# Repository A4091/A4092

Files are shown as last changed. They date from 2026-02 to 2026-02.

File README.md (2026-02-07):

# A4092 — A Modern Successor to the A4091

The A4092 is a modern re-implementation of Dave Haynie's classic A4091 Zorro
III SCSI controller for the Commodore Amiga. It retains a lot of the proven
architecture and the NCR/LSI 53C710 SCSI controller at its core, while
replacing obsolete and unobtainable components with modern equivalents that are
more readily available today.

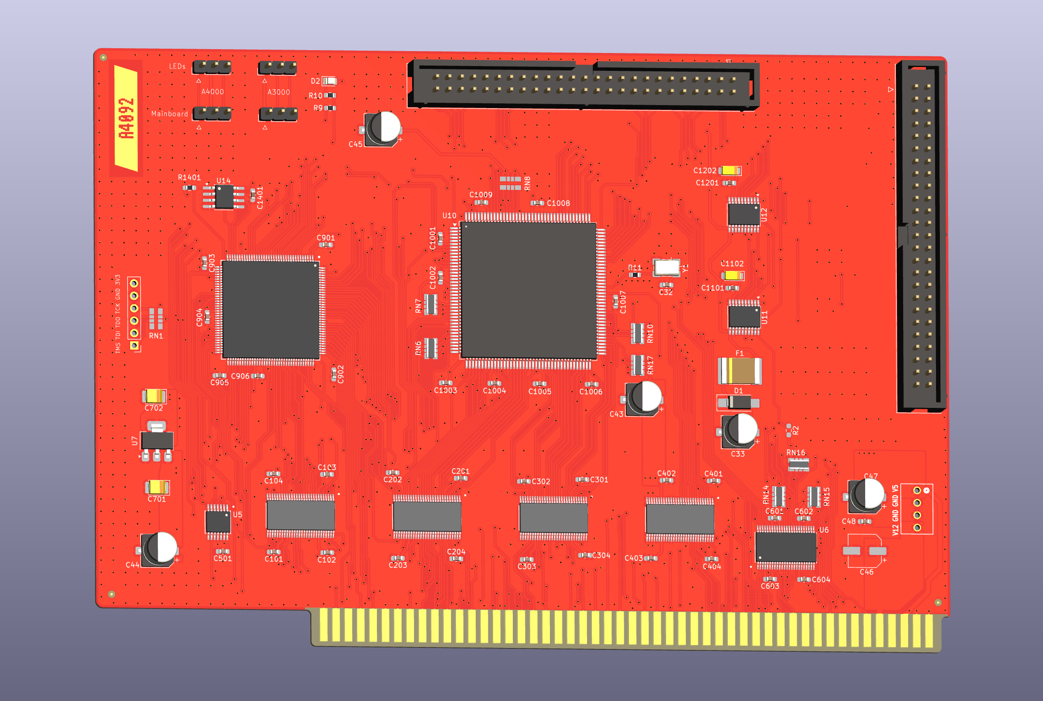
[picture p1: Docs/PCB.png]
PCB


And also as a real PCB (REV A):

Real PCB

## What's New

### CPLD Instead of GALs

The original A4091 used eight discrete GALs (ATF22V10 and similar) programmed
with WinCUPL to implement all bus interface, AutoConfig, address decoding,
arbitration, and SCSI control logic. The A4092 consolidates all of this
into a single Xilinx XC95144XL CPLD. This brings several advantages:

- Field-updatable logic — no need to pull and reprogram individual GAL chips
- No soldering and no sockets required for upgrading the liogic.
- More logic resources and routing flexibility than the original GAL array
- Eliminates dependence on increasingly scarce GAL parts
- The original WinCUPL equations have been rewritten from scratch in Verilog for the CPLD

### SPI Flash Instead of EPROM

The parallel EPROM used for the A4091's boot ROM has been replaced with SPI
Flash memory. Firmware updates no longer require a UV eraser and a dedicated
EPROM programmer — the flash can be reprogrammed in-system.

### Modern SMD Packages

Where the original A4091 used through-hole, PLCC and SOIC packages, the A4092 uses
TSSOP and other modern surface-mount packages (such as 0603 passives). This
reduces the board footprint, improves signal integrity and aligns with current
PCB assembly capabilities.

### Designed for Current Manufacturing

The A4092 is designed to be manufactured with services like JLCPCB or PCBway, using
(mostly) components that are in current production and readily sourced. No hunting for
NOS parts or pulling chips from donor boards.

### AutoConfig in the CPLD

The AutoConfig logic — previously spread across multiple GALs — is now
integrated into the CPLD alongside the rest of the glue logic, resulting in a
cleaner and more maintainable design. 

## What Stays the Same

The A4092 is not a redesign — it is a re-implementation. The core architecture is unchanged:

- NCR/LSI 53C710 SCSI controller
- Zorro III bus interface with the same timing and protocol behavior
- Full compatibility with existing A4091 device drivers and ROM images
- Active SCSI termination
- Internal and external SCSI connectors

## Revisions

- **Revision C** - This is the revision you should build.
- **Revision A** - needs [a number of reworks](https://docs.google.com/document/d/1CN8fwkUjfMrxxf_vMktpmiZ6GXSNA-jGrsVZTGIDl_o/edit?usp=sharing)

## Related Projects

- **A4091** — The original Commodore design by Dave Haynie (1992)

## License



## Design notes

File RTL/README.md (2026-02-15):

# A4092 CPLD RTL

Verilog RTL for the A4092 Zorro III SCSI controller. The design targets a
**Xilinx XC95144XL** CPLD and bridges a **NCR 53C710** (or 53C770) SCSI
controller to the Amiga Zorro III bus. It is a modern re-implementation of the
glue logic found on the Commodore A4091.

## Architecture Overview

```
                        Zorro III Bus
                 ───────────┬───────────
                            │
                     ┌──────┴──────┐
                     │  A4092 CPLD │
                     │  (XC95144XL)│
                     │             │
          ┌──────────┤  Top-level  ├───────────┐
          │          │  A4092.v    │           │
          │          └──┬───┬───┬──┘           │
          │             │   │   │              │
     ┌────┴────┐  ┌─────┴┐  │ ┌-┴─────┐  ┌─────┴────┐
     │Autoconf │  │Buffer│  │ │ DMA   │  │Interrupt │
     │         │  │Ctrl  │  │ │Arbiter│  │Handling  │
     └─────────┘  └──────┘  │ └───┬───┘  └──────────┘
                            │     │
                       ┌────┴-┐ ┌─┴──────┐
                       │SCSI  │ │  DMA   │
                       │Access│ │ Master │
                       └──────┘ └────────┘
                           │
                    ───────┴───────
                     NCR 53C710/770
```

## Module Descriptions

| Module | File | Description |
|---|---|---|
| **A4092** | `A4092.v` | Top-level module. Clock generation, address decoding, data bus muxing, and Zorro III signal assignment. |
| **autoconfig** | `autoconfig.v` | Zorro III Autoconfig (plug-and-play). Presents manufacturer/product ID and accepts base address assignment from the OS. |
| **buffercontrol** | `buffercontrol.v` | Controls external data and address bus buffers -- output enable, direction, and data latching for both slave and DMA master cycles. |
| **dmaarbiter** | `dmaarbiter.v` | Arbitrates between the NCR SCSI chip's DMA requests and the Zorro III bus. Handles bus request/grant handshaking on the 7 MHz arbitration clock. |
| **dmamaster** | `dmamaster.v` | Generates Zorro III bus master cycle timing (FCS, DOE, DS) when the NCR chip performs DMA transfers. |
| **scsiaccess** | `scsiaccess.v` | Manages CPU (slave) access to NCR SCSI registers. Generates AS/DS/SREG strobes to the SCSI chip and converts SLACK to Zorro DTACK. |
| **interrupthandling** | `interrupthandling.v` | Handles SCSI interrupts. Supports both directly-forwarded INT2 and the Zorro III Quick Interrupt protocol with programmable interrupt vectors. |
| **sidregister** | `sidregister.v` | Software-accessible SCSI ID / configuration register. Replaces the hardware DIP switch with a virtual register; also controls external SCSI bus termination. |
| **spirom** | `spirom.v` | SPI flash ROM interface. Bit-bangs SPI read commands to serve firmware to the CPU over Zorro III. |
| **parallelrom** | `parallelrom.v` | Parallel flash ROM interface (active when `USE_SPIROM` is not defined). Directly drives CE/OE/WE lines with configurable wait states. |

## Address Map

Within the card's Autoconfig-assigned 16 MB address space:

| Offset | Range | Peripheral |
|---|---|---|
| `$000000` | `$000000 - $7FFFFF` | Boot ROM (SPI or parallel flash) |
| `$800000` | `$800000 - $87FFFF` | NCR 53C710/770 SCSI registers |
| `$880000` | `$880000 - $8BFFFF` | Interrupt control register |
| `$8C0000` | `$8C0000 - $8FFFFF` | SCSI ID / configuration register |

Address decoding uses `A[23]`, `A[19]`, and `A[18]` in the top-level module.

## Compile-Time Options

Defined at the top of `A4092.v`:

| Define | Default | Description |
|---|---|---|
| `USE_SPIROM` | Defined | Use SPI flash for boot ROM. Undefine for parallel flash. |
| `USE_DIP_SWITCH` | Undefined | Use a physical DIP switch for SCSI ID instead of the virtual `sidregister`. |
| `A22_21_MISSING` | Defined | Address lines A22/A21 are not routed to the CPLD; synthesizes workaround logic. |
| `53C770` | Undefined | When defined, BCLK is an external input from a 53C770. Otherwise the CPLD generates 25 MHz by dividing the 50 MHz oscillator. |

## Autoconfig Identity

| Field | Value |
|---|---|
| Manufacturer ID | 514 (Commodore) |
| Product ID | 84 |
| Serial | 14 |
| ROM vector offset | 512 ($200) |

## Clocks

- **CLK_50M** -- 50 MHz oscillator input, used by SPI ROM and interrupt logic.
- **CLK** (25 MHz) -- Generated internally by dividing CLK_50M by 2 (or external input when `53C770` is defined). Drives the NCR SCSI chip as BCLK and clocks most bus-cycle state machines.
- **C7M** (7.09 MHz) -- Zorro III arbitration clock from the backplane. Used exclusively by the DMA arbiter for bus request timing.

## Building

Requires the Xilinx ISE toolchain (XST, ngdbuild, cpldfit, hprep6).

```
make                 # Synthesize and produce A4092.jed
make timing          # Run timing analysis
make flash           # Program the CPLD via JTAG
make clean           # Remove build artifacts
```

The Makefile supports `USE_DIP_SWITCH=1` to build with hardware DIP switch support.

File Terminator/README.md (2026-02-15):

# A4092 Active SCSI Terminator Case

A 3D-printable snap-fit enclosure for the A4092 (and A4091) Active SCSI Terminator PCB, designed in [OpenSCAD](https://openscad.org/) using the [YAPP Box](https://github.com/mrWheel/YAPP_Box) generator v3.

## Features

- Two-piece snap-fit design (base + lid), no screws required
- Cutout for the IDC50 SCSI connector
- Label embossed/debossed on the lid
- PCB standoffs with alignment pins

## Variants

STL files are provided for several combinations:

| Option | Choices |
|---|---|
| Device | A4091, A4092 |
| Process | FDM (debossed label), Resin/SLA (embossed label) |
| Edge style | Round, Chamfered |

Pre-built STL files follow the naming convention:

```
<device>_terminator_<part>_<process>_<style>.stl
```

For example: `A4092_terminator_lid_fdm_chamfered.stl`

## Building from Source

### Prerequisites

- [OpenSCAD](https://openscad.org/) (the Makefile expects the macOS .app bundle by default)
- [YAPP Box generator v3](https://github.com/mrWheel/YAPP_Box) checked out at `../YAPP_Box/`

### Generating STL Files

```bash
make          # Build all variants
make clean    # Remove generated STL files
```

The Makefile generates all combinations of part, process, and style automatically. To change which devices are built, edit the `DEVICES` variable in the Makefile.

## Printing Tips

- **FDM**: Labels are debossed (engraved into the surface). Use the `fdm` STL variants.
- **Resin/SLA**: Labels are embossed (raised from the surface). Use the `resin` STL variants.
- No supports should be needed for either the base or lid when printed in their default orientation.

## Design Parameters

Key dimensions (defined in `A4092_terminator.scad`):

| Parameter | Value |
|---|---|
| PCB size | 69.6 x 24 mm |
| Wall thickness | 2.0 mm |
| Base/lid plane thickness | 2.0 mm |
| Ridge height | 4.0 mm |

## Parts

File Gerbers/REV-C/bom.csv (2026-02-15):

Designator | Footprint | Quantity | Value | LCSC Part #
C1001, C1003, C1005, C1007, C1009, C101, C102, C103, C104, C1101, C1201, C1401, C201, C202, C203, C204, C301, C302, C303, C304, C401, C402, C403, C404, C48, C501, C601, C602, C603, C604, C901, C902, C903, C904, C905, C906 | 0603 | 36 | 100nF | C14663
C1002, C1004, C1006, C1008, C32 | 0603 | 5 | 10nF | C57112
C1102, C1202 | CP_EIA-3216-10_Kemet-I_HandSolder | 2 | 4.7uF | C7189
C33, C43, C44, C45, C47 | CP_Elec_6.3x7.7 | 5 | 47uF | C369909
C701 | CP_EIA-3528-15_AVX-H_HandSolder | 1 | 10uF | C7194
C702 | CP_EIA-3528-15_AVX-H_HandSolder | 1 | 22uF | C696813
D1 | D_SMA_Handsoldering | 1 | SS24 | C43381
D2 | 0805 | 1 | LED (green) | C965821
F1 | 2920 | 1 | ASMDC185F/33-2 | C3761950
J1, J5 | IDC-Header_2x25_P2.54mm_Vertical | 2 | Conn_02x25_Odd_Even | C221059
J3 | PinHeader_1x03_P2.54mm_Vertical | 1 | TO-LED | C6332196
J4 | PinHeader_1x03_P2.54mm_Vertical | 1 | TO-MB | C6332196
J8 | PinHeader_1x03_P2.54mm_Vertical | 1 | TO-A3000-LED | C6332196
J9 | PinHeader_1x03_P2.54mm_Vertical | 1 | TO-A3000-MB | C6332196
R10 | 0603 | 1 | 2.2k | C4190
R11 | 0603 | 1 | 22 | C23345
R1401 | 0603 | 1 | 10K | C25804
R9 | 0603 | 1 | 120 | C22787
RN10, RN14, RN15, RN16, RN17, RN6, RN7 | BO_CAY16 | 7 | 1K | C784824
U1, U2, U3, U4 | DGG56 | 4 | SN74ABT16543DGGR | C2865087
U10 | PQFP-160_28x28mm_P0.65mm | 1 | NCR53c710 SCSI Host Controller | C9900133089
U11, U12 | TSSOP-20_4.4x6.5mm_P0.65mm | 2 | DS21S07A | C6602097
U14 | SOIC-8_multi | 1 | W25X40CLSN | C19617
U5 | TSSOP14_5P1X4P5_NEX | 1 | 74LVC07APW_118 | C6051
U6 | DGG48 | 1 | SN74ABT16245ADGGR | C130197
U7 | SOT-223-3_TabPin2 | 1 | AMS1117-3.3 | C6186
U9 | 144-TQFP_XIL | 1 | XC95144XL-TQ144 | C1521137
Y1 | Oscillator_SMD_Fox_FT5H_5.0x3.2mm | 1 | Abracon ACO-50MHz | C7431196

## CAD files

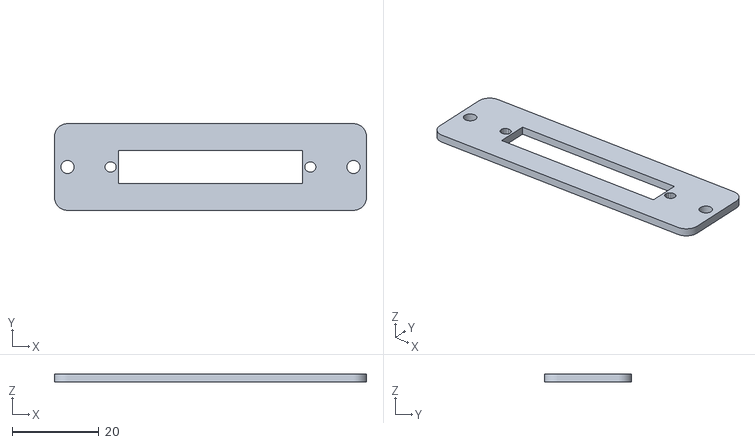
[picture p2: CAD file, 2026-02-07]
Brackets/a4000d_hpdb50.stl
72.0 x 20.0 x 1.80

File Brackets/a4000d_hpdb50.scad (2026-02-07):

$fn = 128;  // smoothness of corners
$thickness = 1.8;
//$holeoffset = -1.3;
$holeoffset = 0;

module rounded_plate(size, radius) {
    hull() {
        for (x = [-1, 1], y = [-1, 1])
            translate([x * (size.x/2 - radius), y * (size.y/2 - radius), 0])
                cylinder(h = size.z, r = radius, center = false);
    }
}

color ("beige") translate ([0,0,0])
    difference () {
        difference() {
            rounded_plate([72, 20, $thickness], radius = 3);
            union() {
                translate ([-33,$holeoffset,-0.1])
                    cylinder(h = $thickness + 0.2, r = 1.5, center = false);
                translate ([33,$holeoffset,-0.1])
                    cylinder(h = $thickness+0.2, r = 1.5, center = false);
            }
        };
 
        translate ([-49.1,-11.1,0]) union()
        {
            translate([27.85,7.35,-0.1])
                cube([42.5,7.5,$thickness + 0.2]);
            translate([26.05,11.1,-0.1])
            {
                scale([2.6/2.4, 1, 1])
                    cylinder(d=2.4, h=$thickness + 0.2, $fn=15);
                translate([46.1,0,0])
                    scale([2.6/2.4, 1, 1])
                        cylinder(d=2.4, h=$thickness + 0.2, $fn=15);
            }
        }
    }

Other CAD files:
Terminator/A4092_terminator.scad

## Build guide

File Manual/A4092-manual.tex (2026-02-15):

%\documentclass[10pt, twoside, openright]{report}
\documentclass[10pt, twoside, openany]{report}
\usepackage[paperwidth=5.5in, paperheight=8.5in,
  left=1.5cm, right=1.5cm, top=6mm, bottom=6mm,
  bindingoffset=0.5cm,
  includehead, includefoot,
  headheight=23pt, headsep=6pt, footskip=24pt]{geometry}
\usepackage[utf8]{inputenc}
\usepackage[T1]{fontenc}
\usepackage{helvet} % Helvetica for a classic technical feel
\renewcommand{\familydefault}{\sfdefault}

% Colors based on your box art
\usepackage{xcolor}
\definecolor{boxblack}{cmyk}{0.6,0.4,0.4,1} % Rich black (C60 M40 Y40 K100)
\definecolor{cranered}{cmyk}{0,1,1,0.28} % Origami Red (converted from #B80000)
\definecolor{lightgrey}{cmyk}{0,0,0,0.12} % Light grey (converted from #E0E0E0)
\definecolor{warninggrey}{cmyk}{0,0,0,0.06} % Warning grey (converted from #F0F0F0)

% Graphics and Formatting
\usepackage{graphicx}
% SVGs are converted to PDFs by Makefile using Inkscape
\usepackage{titlesec}
\usepackage{fancyhdr}
\usepackage{array}    % Column formatting (e.g. >{\centering})
\usepackage{booktabs} % Professional tables
\usepackage{longtable}
\usepackage{pagecolor} % For the black cover
\usepackage{caption}
\usepackage{float}
\usepackage{framed}
\usepackage{enumitem}
\usepackage[colorlinks=false, pdfborder={0 0 0}]{hyperref}
\setlist[itemize]{itemsep=3pt, parsep=0pt, topsep=4pt}
\setlist[enumerate]{itemsep=2pt, parsep=0pt, topsep=4pt}

% No paragraph indentation
\setlength{\parindent}{0pt}
\setlength{\parskip}{0.5em}

% Warning and Caution box styles
\newenvironment{warningbox}{%
  \def\FrameCommand{\fboxsep=3mm \fboxrule=1pt \fcolorbox{black}{warninggrey}}%
  \MakeFramed{\advance\hsize-\width \FrameRestore}}%
{\endMakeFramed}

\newenvironment{cautionbox}{%
  \begin{quote}\itshape\textbf{Caution:} }%
{\end{quote}}

% Header/Footer Configuration
\pagestyle{fancy}
\fancyhf{}
\fancyhead[LE,RO]{\textbf{A4092 User's Guide}}
\fancyhead[RE,LO]{\nouppercase{\leftmark}}
\fancyfoot[C]{\thepage}
\renewcommand{\headrulewidth}{0.4pt}

% Section styling
\titleformat{\chapter}[hang]{\Huge\bfseries\color{cranered}}{}{0pt}{}
\titlespacing*{\chapter}{0pt}{-28pt}{20pt}
\titleformat{\section}{\Large\bfseries}{}{0pt}{}
\titleformat{\subsection}{\large\bfseries}{}{0pt}{}

\begin{document}

% =============================================================================
% COVER PAGE (Black with Red Cranes)
% =============================================================================
\begin{titlepage}
    \newpagecolor{boxblack}
    \color{white}
    \thispagestyle{empty}

    \begin{center}
        \vspace*{1cm}
        

        \vspace{1cm}

        {\fontsize{60}{70}\selectfont \textbf{\textcolor{cranered}{A4092}}} \\
        \vspace{0.5cm}
        {\Huge \textbf{Zorro III SCSI-2}} \\
        \vspace{0.2cm}
        {\LARGE Host Adapter}

        \vfill

        \rule{0.8\textwidth}{0.5pt} \\
        \vspace{0.5cm}
        {\small HIGH PERFORMANCE STORAGE SOLUTION FOR AMIGA COMPUTERS}
        \vspace{1cm}
    \end{center}
\end{titlepage}

% =============================================================================
% FRONT MATTER (White background returns)
% =============================================================================
\nopagecolor
\color{black}

% Blank page
\newpage
\thispagestyle{empty}
\mbox{}

% Reset page counter so cover pages don't count
\setcounter{page}{0}

% Warning page
\newpage
\thispagestyle{empty}
\vspace*{2cm}
\begin{warningbox}
\begin{center}
{\Huge \textbf{WARNING}}
\end{center}

\vspace{0.5cm}

Installation information in this document is for reference only. All installation of internal optional devices or equipment including third-party optional devices or equipment, should be performed by an experienced and knowledgeable technician. All servicing or upgrading of original or optional devices or equipment should also be performed by an experienced and knowledgeable technician.

\vspace{0.5cm}

\textbf{UNAUTHORIZED INSTALLATION, SERVICING OR UPGRADING MAY VOID YOUR WARRANTIES.}
\end{warningbox}

\vspace{2cm}

\noindent This manual provides a general description of various product configurations and features currently planned for inclusion in the product line. The configurations and features described may not be available or otherwise apply to your particular system.

% Copyright page
\newpage
\thispagestyle{empty}

\small
\noindent Copyright \copyright\ 2026 by Stefan Reinauer. This document is licensed under the Creative Commons Attribution-ShareAlike 4.0 International License (CC BY-SA 4.0). You may copy, distribute, and modify this work, provided you give appropriate credit and distribute any modified versions under the same license. See: \url{https://creativecommons.org/licenses/by-sa/4.0/}

\vspace{0.3cm}

\noindent With this document no warranties or representations, either expressed, or implied, are made with respect to the products described herein. The information presented herein is being supplied on an ``AS IS'' basis and is expressly subject to change without notice.

\vspace{0.3cm}

\noindent Amiga is a trademark of Amiga Corporation. Original text based on Commodore Part No 371167-01.

\vspace{0.3cm}

\noindent \textbf{NOTE:} The A4092 is a community-developed open source hardware project and has not been independently tested for regulatory compliance (FCC, CE, etc.). The original Commodore A4091, on which this design is based, was certified to comply with FCC Class B limits. As with any electronic device, this equipment may generate radio frequency energy. If interference to radio or television reception occurs, standard mitigation techniques such as repositioning the receiving antenna, increasing separation from the equipment, or using shielded cables may help.

\normalsize

\tableofcontents

% =============================================================================
% CHAPTER 1: A4092 SCSI HOST ADAPTER
% =============================================================================
\chapter{A4092 SCSI Host Adapter}
\label{ch:a4092-scsi-host-adapter}

The A4092 SCSI host adapter is a high-performance board that connects up to seven SCSI devices to your Amiga. The board installs in a Zorro III expansion slot and contains the following features:

\begin{itemize}
    \item Full Zorro III implementation
    \item SCSI-2 implementation
    \item SCSI internal connector and ribbon cable
    \item High density SCSI-2 external connector
    \item Direct Memory Access (DMA) for fast transfers
\end{itemize}

This guide tells you how to:

\begin{itemize}
    \item Check for Zorro III compatibility
    \item Install the A4092 board in an Amiga
    \item Configure SCSI addresses and termination
    \item Install internal and external SCSI devices
    \item Configure a hard drive
\end{itemize}

\newpage

% =============================================================================
% ABOUT OPEN SOURCE
% =============================================================================
\section{About Open Source}
\label{sec:about-open-source}

The A4092 is a community-driven project built on the belief that hardware should be accessible, repairable, and improvable by anyone. We believe in the right to repair and for anyone to make their own version. That is why this product, including all hardware and software, is 100\% open source.

All design files, schematics, PCB layouts, firmware, and software are freely available. You are welcome to:

\begin{itemize}
    \item Study how the board works
    \item Build your own A4092 from the published designs
    \item Modify and improve the design for your own needs
    \item Share your improvements with the community
\end{itemize}

For access to the source files and to contribute, visit the project repository at \url{https://github.com/A4091/a4092}.

% =============================================================================
% RELATED DOCUMENTS
% =============================================================================
\section{Related Documents}
\label{sec:related-documents}

Most instructions and illustrations in this guide refer to an Amiga 4000 Desktop system.
Along with this guide, you will need to refer to your system's hardware user
guide and software guides, including the \textit{Workbench User's Guide}. You
should also check the additional documentation on the A4092 Support disk.

% =============================================================================
% BEFORE YOU BEGIN
% =============================================================================
\section{Before You Begin}
\label{sec:before-you-begin}

Select a clean, well-lit work space. Place your system unit on a stable work surface large enough to accommodate the components of the system unit you remove and replace.

As you work with your system you must:

\begin{itemize}
    \item Protect yourself from electrical shock by turning the Amiga off, unplugging, and disconnecting all cables before removing the cover.
    \item Protect your system from electrostatic discharge (ESD).
\end{itemize}

% =============================================================================
% ESD PRECAUTIONS
% =============================================================================
\section{ESD Precautions}
\label{sec:esd-precautions}

Integrated circuit (IC) chips are sensitive to static electricity. When handling electronic components containing IC chips, including expansion boards and RAM modules, always take precautions to reduce the chances of electrostatic discharge (ESD) harming the components.

Touching a nearby grounded metal surface before touching a component drains static electricity, reducing the likelihood of ESD damage.

To protect your system from ESD, observe these precautions:

\begin{itemize}
    \item Do not unpack any computer components that are wrapped in anti-static packing material until you are ready to install them.
    \item Discharge any static buildup as you work by periodically touching an unpainted metal surface, e.g. on a radiator. This is particularly important before you unpack a new computer component.
    \item Handle each component carefully. Avoid touching card edge connectors, electrical component connectors, and contact points.
\end{itemize}

% =============================================================================
% CHECKING FOR ZORRO III COMPATIBILITY
% =============================================================================
\section{Checking for Zorro III Compatibility}
\label{sec:checking-zorro-iii}

To ensure that your Commodore Amiga 3000 or 4000 system is compatible with the
A4092 SCSI Host Adapter board, the Super Buster chip on your system motherboard
must be (at least) revision 11 (part number 390539-11 or later) for stable Zorro III DMA operation.

\begin{warningbox}
\textbf{Warning:} Turn off your system and unplug the Amiga before checking the
revision of the chip. Disconnect cables for all external peripherals.
\end{warningbox}

To determine whether the chip installed in your system is the correct revision:

\begin{enumerate}
    \item Remove the system cover as described in the \textit{A4000 User's Guide} or \textit{Introducing the Amiga 3000} depending on your model.
    \item Carefully remove any expansion boards that obstruct your view of the chip, shown in Figure~\ref{fig:motherboard}. Refer to the \textit{A4000 User's Guide} or \textit{Introducing the Amiga 3000} for detailed instructions on removing expansion boards from your Amiga model.
    \item The chip can either be socketed or surface-mounted (soldered) on the motherboard. Check the part number on the chip. If the suffix is nine or less, it must be replaced.
    \item Replace the expansion boards.
    \item If your system contains the correct version of the chip and you have already installed the A4092 SCSI host adapter, replace the system cover and reconnect peripheral equipment. If you haven't installed the SCSI host adapter, you can install it now as described in this guide.
    \item Replace the system cover.
\end{enumerate}

\begin{cautionbox}
Some board revisions use a socketed chip that can be replaced directly. Others
require soldering and advanced repair skills. If you are unsure which version
you have, or how to safely upgrade, consult an experienced Amiga hardware technician or a skilled member of the Amiga repair community.
\end{cautionbox}

\begin{figure}[ht]
    \centering
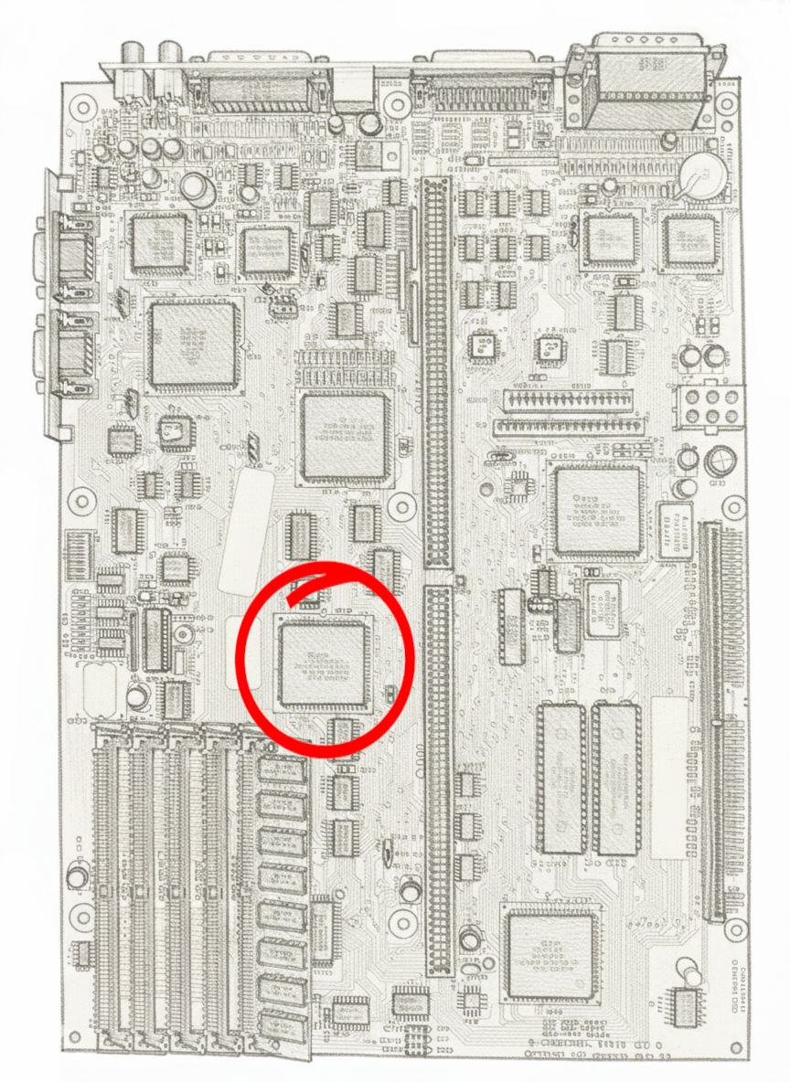
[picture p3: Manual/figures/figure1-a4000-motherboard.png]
    
    \caption{Super Buster Location on A4000}
    \label{fig:motherboard}
\end{figure}

% =============================================================================
% CHAPTER 2: INSTALLING THE A4092
% =============================================================================
\chapter{Installing the A4092}
\label{ch:installing-the-a4092}

You can connect up to seven SCSI devices (including hard drives, scanners, tape units and CD-ROMs) to your Amiga using the A4092 board illustrated in Figure~\ref{fig:board}.

\begin{figure}[ht]
    \centering
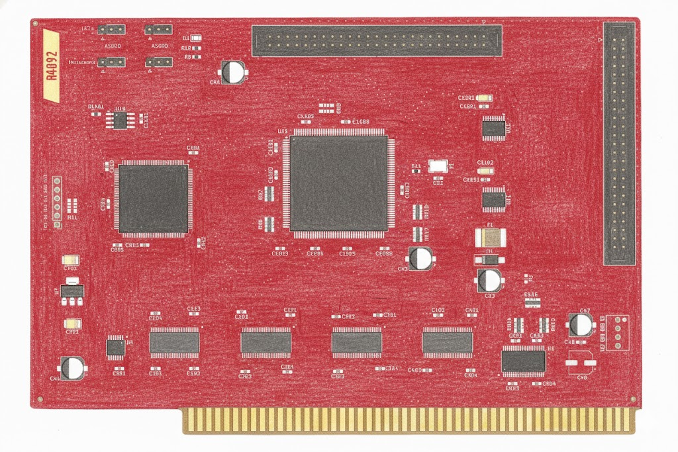
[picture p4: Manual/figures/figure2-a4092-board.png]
    
    \caption{The A4092 SCSI Host Adapter Board}
    \label{fig:board}
\end{figure}

You connect internal SCSI devices to the internal connector with the ribbon cable provided.
In order to connect external SCSI devices, you will have to connect the
A4092 External Connector Bracket to the A4092 using a 50pin SCSI cable.
You connect one external device to the external SCSI connector on the bracket, then connect additional devices in a chain from the first device.

\begin{figure}[ht]
    \centering
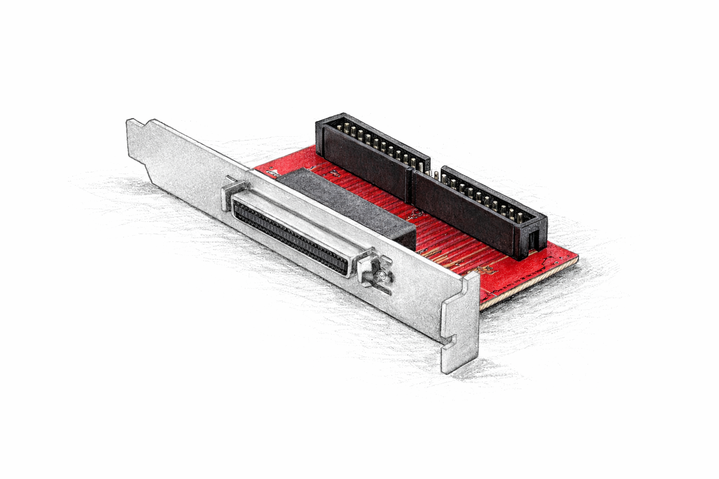
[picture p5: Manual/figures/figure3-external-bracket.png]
    
    \caption{The A4092 External Connector Bracket}
    \label{fig:bracket}
\end{figure}

\newpage

% =============================================================================
% INSTALLATION STEPS
% =============================================================================
\section{Installation Steps}
\label{sec:installation-steps}

Installing the A4092 board is similar to installing any expansion board in your system. Before you install the board, you should review the configuration options described in ``Configuring the A4092''.

To install the board, do the following:

\begin{enumerate}
    \item Turn off the Amiga's power switch, remove all connecting cables and disconnect the Amiga from the AC power outlet.
    \item Remove the Amiga cover.
    \item Remove the cover plate of the slot in which you intend to install the board. Install the board in any available Zorro III slot.

    \item Look at the 50-pin SCSI ribbon cable, illustrated in Figure~\ref{fig:ribboncable}. Locate the end of the ribbon cable that you will connect to the board. Note that the colored edge of the cable indicates pin 1.

    \item Connect the ribbon cable to the board, aligning pin 1 on the cable connector (colored edge) with pin 1 on the board as illustrated in Figure~\ref{fig:ribbontoboard}.

    \item Insert the board in the slot and attach with the screw from the slot cover plate.

    \item Unplug the hard disk front panel LED cable from the hard disk LED connector on the motherboard (if connected) and plug it into the LEDs header on the A4092 board, illustrated in Figure~\ref{fig:ledheaders}. Use the header labelled A4000 or A3000 depending on your system. On the Amiga 3000, polarity matters---check the triangle marking next to the A3000 LED header in Figure~\ref{fig:ledheaders} to ensure correct orientation.

    \item In order to connect the LED signals from the motherboard, install the LED jumper cable (supplied with the A4092 board) from the motherboard LED connector (CN351 on A4000D, CN302 on A3000D) to the Mainboard header on the A4092 board, illustrated in Figure~\ref{fig:ledheaders}.

\begin{figure}[ht]
    \centering
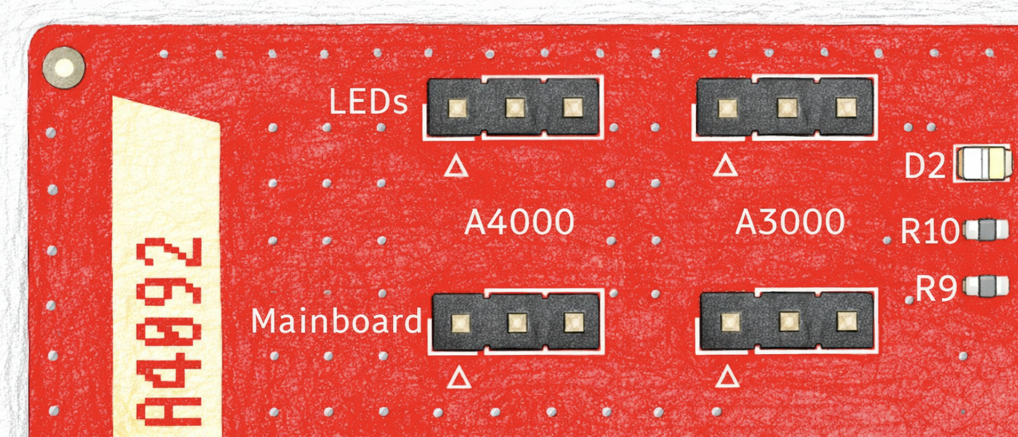
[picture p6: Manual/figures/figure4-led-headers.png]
    
    \caption{LED Header Connections on the A4092}
    \label{fig:ledheaders}
\end{figure}

    \item Install any internal SCSI devices (optional) as described in ``Installing Internal SCSI Devices''.

    \item Replace the Amiga cover.

    \item Install any external SCSI devices (optional) as described in ``Installing External SCSI Devices''.

    \item Reattach connecting cables, reconnect the Amiga to the AC power outlet and turn the power switch on.

    \item The Workbench screen should show a disk icon for each partitioned hard drive you connected. If you installed a new hard drive, see ``Configuring a Hard Drive''.
\end{enumerate}

\begin{figure}[ht]
    \centering
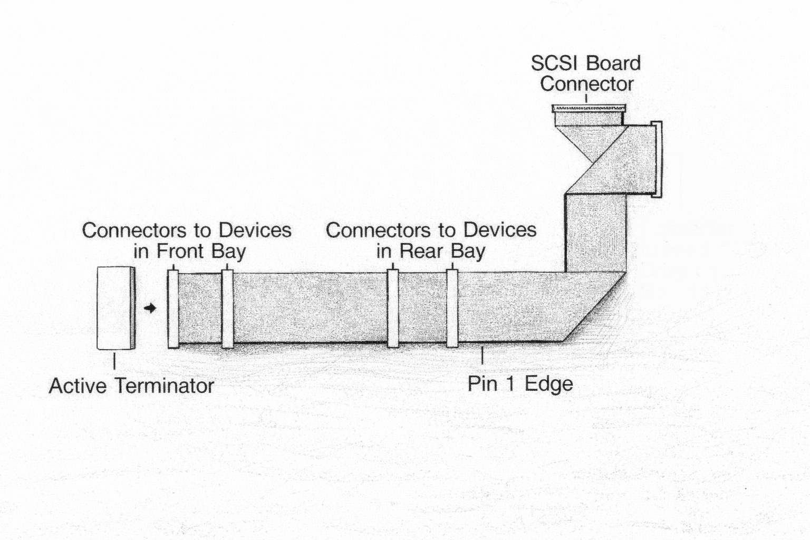
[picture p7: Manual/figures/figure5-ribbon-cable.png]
    
    \caption{50-pin SCSI Ribbon Cable}
    \label{fig:ribboncable}
\end{figure}

\begin{figure}[ht]
    \centering
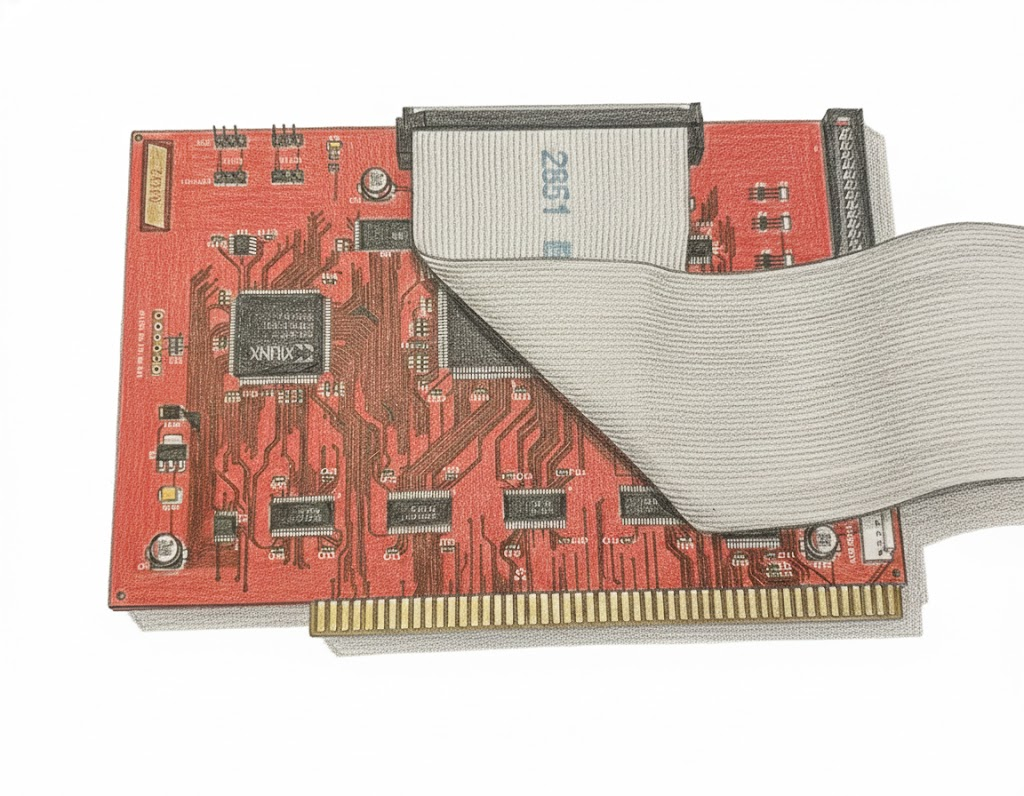
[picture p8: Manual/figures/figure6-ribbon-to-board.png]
    
    \caption{Connecting the Ribbon Cable to the Board}
    \label{fig:ribbontoboard}
\end{figure}

\begin{cautionbox}
It is essential to align pin 1 on the cable with pin 1 on your SCSI device. The folds in the provided ribbon cable enable you to easily align pin 1 on the cable with pin 1 on most devices.

Some SCSI devices have reversed the location of pin 1. If you have such a device, you must carefully manipulate the cable to ensure that pin 1 alignment is correct. Failure to align pin 1 can result in damage to the SCSI device.
\end{cautionbox}

% =============================================================================
% CHAPTER 3: CONFIGURING THE A4092
% =============================================================================
\chapter{Configuring the A4092}
\label{ch:configuring-the-a4092}

The A4092 is configured through a boot menu that allows you to control the SCSI address of the board as well as features such as SCSI Fast Bus, short/long spinup, synchronous mode and external termination.

% =============================================================================
% THE BOOTMENU
% =============================================================================
\section{The Bootmenu}
\label{sec:bootmenu}

You can enter the A4092 boot menu by pressing the right mouse button or the DEL key during system startup. The boot menu provides access to all configuration options for the board.

\begin{figure}[ht]
    \centering
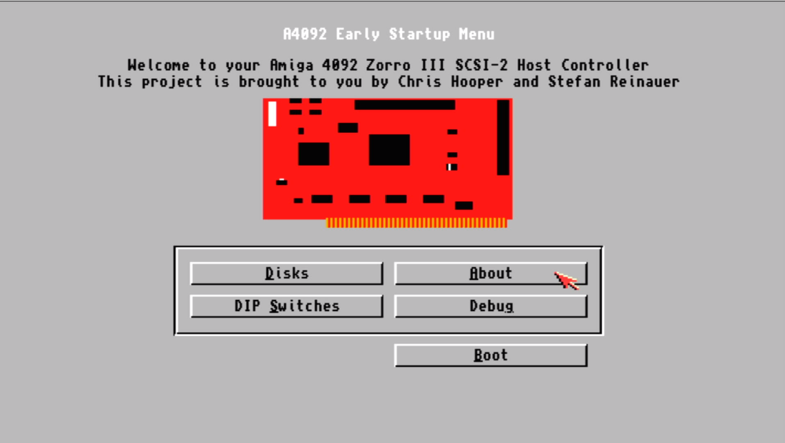
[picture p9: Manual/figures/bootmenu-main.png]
    
    \caption{A4092 Boot Menu Main Screen}
    \label{fig:bootmenu-main}
\end{figure}

The boot menu contains four main buttons:

\begin{itemize}
    \item \textbf{Disks} --- View and select connected SCSI devices
    \item \textbf{DIP Switches} --- Configure board settings
    \item \textbf{About} --- Display version and credits information
    \item \textbf{Debug} --- Access advanced debugging options
\end{itemize}

Press the \textbf{Boot} button to exit the boot menu and continue the system startup.

% =============================================================================
% DISKS
% =============================================================================
\section{Disks}
\label{sec:disks}

The Disks screen displays all SCSI devices detected on the bus. From here you can view device information and select which device to boot from.

\begin{figure}[ht]
    \centering
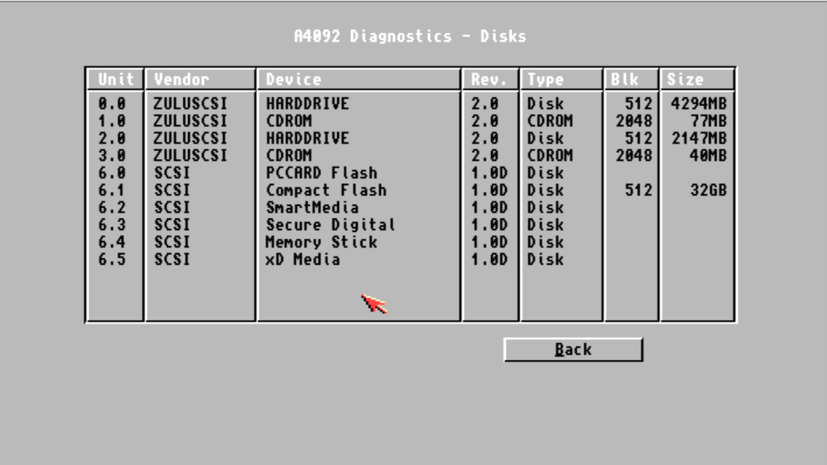
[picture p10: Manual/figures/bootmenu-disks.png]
    
    \caption{A4092 Boot Menu Disks Screen}
    \label{fig:bootmenu-disks}
\end{figure}

% =============================================================================
% DIP SWITCH
% =============================================================================
\section{DIP Switches}
\label{sec:dip-switches}

Unlike its predecessors, the A4092 does not have physical DIP switches on the board. Instead, all settings are configured through virtual DIP switches in the boot menu. These settings are stored in non-volatile memory and persist across reboots.

\begin{figure}[H]
    \centering
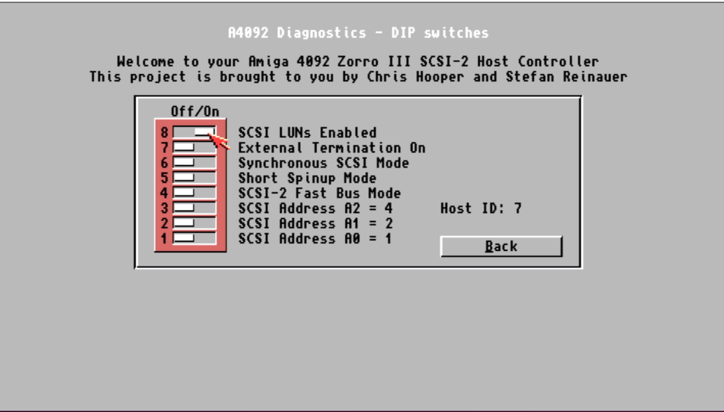
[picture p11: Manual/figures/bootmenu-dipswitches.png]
    
    \caption{A4092 Boot Menu DIP Switches Screen}
    \label{fig:bootmenu-dipswitches}
\end{figure}

The virtual DIP switch provides eight switches with two settings each: OFF (open) and ON (closed). The default setting for all eight switches is OFF.

The following table explains the purpose of each switch; note that switches 1, 2 and 3 are used in combination.

\begin{center}
\small
\setlength{\tabcolsep}{4pt}
\begin{longtable}{@{}p{2.0cm}>{\centering\arraybackslash}p{1.0cm}p{2.0cm}p{4.5cm}@{}}
\toprule
\textbf{Switch} & \textbf{Default} & \textbf{Setting} & \textbf{Function} \\ \midrule
\endfirsthead
\toprule
\textbf{Switch} & \textbf{Default} & \textbf{Setting} & \textbf{Function} \\ \midrule
\endhead

\textbf{SCSI \newline Address} \newline 1, 2, 3 & OFF & \raisebox{-0.4\height}{} & Set the SCSI address for the board. See ``SCSI Addresses'' for more information. \\ \addlinespace

\textbf{SCSI \newline Fast Bus} \newline 4 & OFF & \raisebox{-0.4\height}{} & OFF indicates that the SCSI Fast Bus feature is enabled. Set this switch to ON if none of your SCSI devices support SCSI Fast Bus. \\ \addlinespace

\textbf{Short/Long Spinup} \newline 5 & OFF & \raisebox{-0.4\height}{} & OFF indicates that your system uses the standard spinup (booting) time. Set this switch to ON to request a longer booting period. \\ \addlinespace

\textbf{Synchronous Mode} \newline 6 & OFF & \raisebox{-0.4\height}{} & OFF indicates that the synchronous mode feature is enabled. Set this switch to ON to disable synchronous mode. \\ \addlinespace

\textbf{External \newline SCSI \newline Termination} \newline 7 & OFF & \raisebox{-0.4\height}{} & OFF indicates that you do not have any external devices. This activates the terminator on the board. Set to ON when you install an external device. \\ \addlinespace

\textbf{Logical Unit (LUN) Enable} \newline 8 & OFF & \raisebox{-0.4\height}{} & OFF indicates that unit 0 is the only unit recognized. Set this switch to ON to enable the system to recognize 1--6 as LUNs. \\
\bottomrule
\end{longtable}
\end{center}

% =============================================================================
% SCSI ADDRESSES
% =============================================================================
\section{SCSI Addresses}
\label{sec:scsi-addresses}

Each SCSI device controlled by the board must have a unique identifier known as the SCSI address. The board must also have a SCSI address. SCSI addresses range from 0 to 7 and must be unique (two devices cannot share an address; a device and the board cannot share an address).

Before you begin installing the board and/or SCSI devices, you must choose the
SCSI address for each device in the SCSI chain. For example, select 7 as the address for the board (the default address set at the factory), 0 and 1 for two internal devices, and 4 for an external device.

Jumpers or switches on a SCSI device determine the SCSI bus identification (SCSI address) for the device. Refer to the device documentation to set the SCSI address for each device.

The first three DIP switches on the board determine the board's SCSI address. If you choose to change the SCSI address from the default, set switches 1, 2 and 3 according to the following table.

\begin{table}[ht]
\centering
\caption{SCSI Address Selection (Switches 1--3)}
\label{tab:scsi_addr}
\begin{tabular}{ccccc}
\toprule
\textbf{SCSI Address} & \textbf{Switch 1} & \textbf{Switch 2} & \textbf{Switch 3} & \textbf{Diagram} \\ \midrule
0 & ON & ON & ON & \raisebox{-0.4\height}{} \\
1 & OFF & ON & ON & \raisebox{-0.4\height}{} \\
2 & ON & OFF & ON & \raisebox{-0.4\height}{} \\
3 & OFF & OFF & ON & \raisebox{-0.4\height}{} \\
4 & ON & ON & OFF & \raisebox{-0.4\height}{} \\
5 & OFF & ON & OFF & \raisebox{-0.4\height}{} \\
6 & ON & OFF & OFF & \raisebox{-0.4\height}{} \\
\textbf{7 (default)} & \textbf{OFF} & \textbf{OFF} & \textbf{OFF} & \raisebox{-0.4\height}{} \\
\bottomrule
\end{tabular}
\end{table}

% =============================================================================
% SCSI DEVICE TERMINATION
% =============================================================================
\section{SCSI Device Termination}
\label{sec:scsi-device-termination}

A chain of SCSI devices must have two and only two termination points, one at either end of the chain of devices. A terminator indicates the end of the chain (bus) and protects the SCSI devices from potential failure. For the best results with SCSI Fast Bus enabled (switch 4 set to OFF), the terminator at both ends should be active, rather than passive.

For internal devices, an active terminator is attached to the end of the supplied ribbon cable. Before you install an internal device, remove or deactivate the terminator on the device. Refer to the manufacturer's documentation for terminator information.

If you have no external devices, set switch 7 to OFF. This enables the active termination on the board, since this is the other end of the chain.

If you install external devices:

\begin{enumerate}
    \item Verify that switch 7 is set to ON.
    \item Terminate the last SCSI device in the chain. For best results, use active termination. If the device has termination built in, you can enable it, or you can attach an external terminator. If you use passive termination, SCSI Fast Bus should not be enabled (set switch 4 to ON).
    \item Remove or deactivate the terminator from each external device (except for the last one). Refer to the manufacturer's documentation for terminator information.
\end{enumerate}

% =============================================================================
% DEBUG
% =============================================================================
\clearpage
\section{Debug}
\label{sec:debug}

The Debug screen provides access to advanced options that may be useful for troubleshooting or special configurations.

\begin{figure}[ht]
    \centering
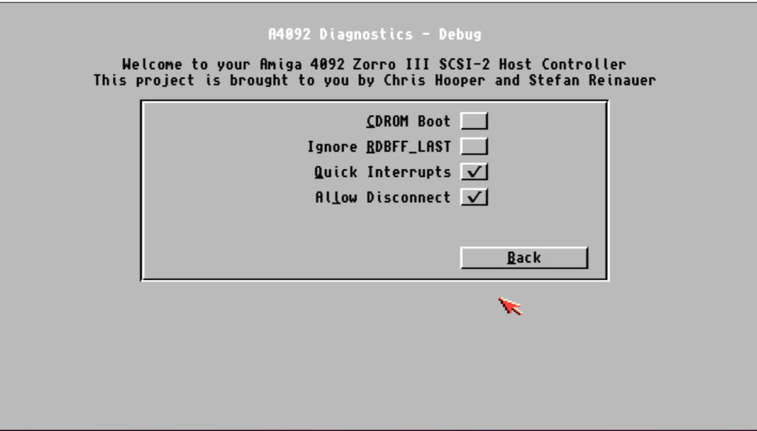
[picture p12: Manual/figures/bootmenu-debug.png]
    
    \caption{A4092 Boot Menu Debug Screen}
    \label{fig:bootmenu-debug}
\end{figure}

The following options are available:

\begin{itemize}
    \item \textbf{CDROM Boot} --- Enable or disable booting from CD-ROM devices. Disabling this can speed up boot time if you do not have a bootable CD-ROM.

    \item \textbf{Ignore RDBFF\_LAST} --- When enabled, the driver ignores the ``Last Drive'' flag in the Rigid Disk Block (RDB) of SCSI devices. Normally, the system stops scanning for additional partitions when it encounters a partition marked as ``last.'' Enabling this option forces the driver to continue scanning, which can be useful if a disk has incorrectly set partition flags.

    \item \textbf{Quick Interrupts} --- Enable or disable Quick Interrupts for Zorro III DMA transfers. Quick Interrupts can provide faster performance but may cause compatibility issues with some accelerator boards. If you experience system instability, try disabling this option.

    \item \textbf{Allow Disconnect} --- Enable or disable SCSI disconnect/reconnect. When enabled, SCSI devices can disconnect from the bus during long operations and reconnect when ready. Keeping this option disabled helps with certain SCSI devices that do not properly support disconnect/reconnect.
\end{itemize}

% =============================================================================
% ABOUT
% =============================================================================
\section{About}
\label{sec:about}

The About screen displays the firmware version number and provides a small homage to the people who brought you the original A4091 as well as this product.

\begin{figure}[H]
    \centering
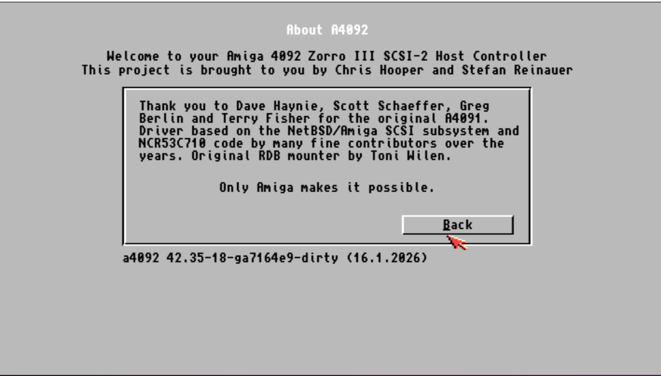
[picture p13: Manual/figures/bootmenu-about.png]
    
    \caption{A4092 Boot Menu About Screen}
    \label{fig:bootmenu-about}
\end{figure}

% dummy new page to get page count to 36
\newpage
\mbox{}
\newpage

% =============================================================================
% CHAPTER 4: INSTALLING INTERNAL SCSI DEVICES
% =============================================================================
\chapter{Installing Internal \newline SCSI Devices}
\label{ch:installing-internal-scsi}

To install an internal SCSI device in one of the drive bays after the board is installed, follow the steps below.

\begin{enumerate}
    \item Set the address jumper of the device to a SCSI address not used by the board or any other SCSI device.

    \item Remove or deactivate the terminator on the device. See ``SCSI Device Termination'' for more information.

    \item Install the device as described in your hardware user's guide and the device installation manual.

    \item Connect the device to the internal power supply.

    \item Repeat steps 1 through 4 until all internal devices are installed.

    \item If you have installed the board for the first time with the ribbon cable attached:
    \begin{enumerate}
        \item[(a)] Remove the brace on top of the daughterboard by removing the screws that attach the brace to the frame of the Amiga, illustrated in Figure~\ref{fig:brace}.
        \item[(b)] Place the ribbon cable across the notch in the daughterboard.
        \item[(c)] Reattach the brace to the Amiga frame.
    \end{enumerate}

    \item Fold the ribbon cable down and guide it towards the back of the Amiga as illustrated in Figure~\ref{fig:ribbontodevices}.

    \item Connect the ribbon cable to the internal SCSI devices as illustrated in Figure~\ref{fig:ribbontodevices}. Be sure to align pin 1 on the cable connector with pin 1 on the device, usually indicated on the device by an arrow ($\leftarrow$) or the number 1.
\end{enumerate}

\begin{figure}[ht]
    \centering
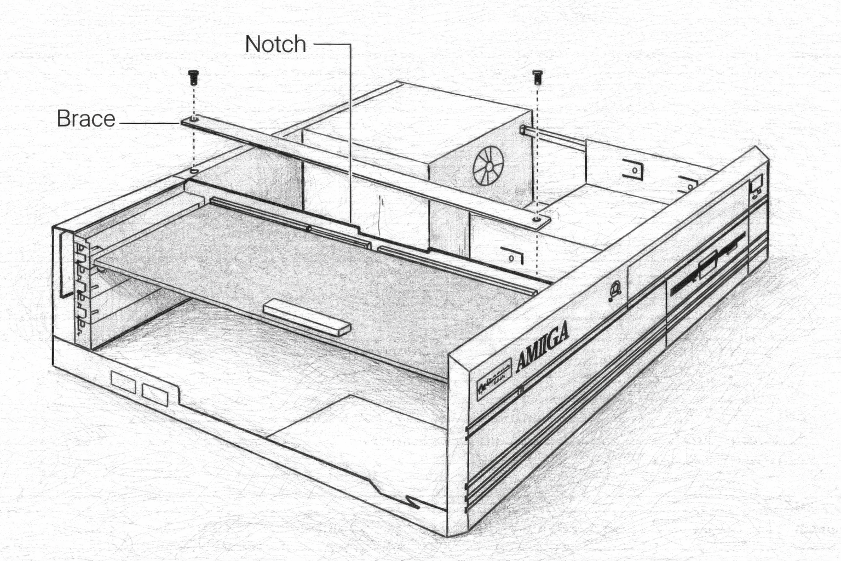
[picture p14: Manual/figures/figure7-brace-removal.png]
    
    \caption{Removing the Brace over the Daughterboard}
    \label{fig:brace}
\end{figure}

\begin{figure}[ht]
    \centering
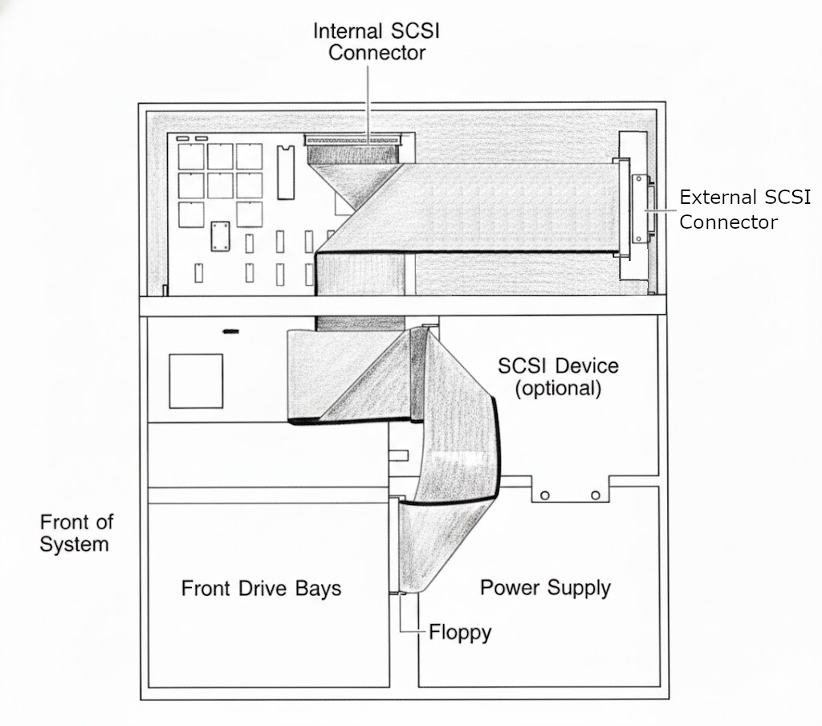
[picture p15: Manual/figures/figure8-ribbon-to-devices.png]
    
    \caption{Connecting the Ribbon Cable to SCSI Devices}
    \label{fig:ribbontodevices}
\end{figure}

\begin{cautionbox}
It is essential to align pin 1 on the cable with pin 1 on your SCSI device. The folds in the provided ribbon cable enable you to easily align pin 1 on the cable with pin 1 on most devices.

Some SCSI devices have reversed the location of pin 1. If you have such a device, you must carefully manipulate the cable to ensure that pin 1 alignment is correct. Failure to align pin 1 can result in damage to the SCSI device.
\end{cautionbox}

% =============================================================================
% CHAPTER 5: INSTALLING EXTERNAL SCSI DEVICES
% =============================================================================
\chapter{Installing External \newline SCSI Devices}
\label{ch:installing-external-scsi}

To connect an external SCSI device after the board is installed in your Amiga, do the following:

\begin{enumerate}
    \item Turn off the power switch and disconnect the Amiga from the AC power outlet.

    \item Verify that switch 7 (External SCSI Termination) on the board is set to ON.

    \item Set the address jumper of the first external SCSI device to an address not used by the board or any internal SCSI device.

    \item Insert the connector of the SCSI device cable (or adapter) into the external SCSI connector on the A4092 External Connector Bracket, illustrated in Figure~\ref{fig:externalconnector}. Align the two pieces to slide straight into one another, since they fit tightly together. Push until the retaining clips are secured. Press the rectangular pieces of metal on either side of the connector to release the retaining clips when inserting or removing the connector.

    \item Set the address jumper of each succeeding SCSI device to an unused SCSI address.

    \item Connect each succeeding SCSI device to the previous SCSI device.

    \item The last external device in the chain requires termination. See ``SCSI Device Termination'' for more information.

    \item Connect each external device to an AC power source.
\end{enumerate}

\begin{figure}[ht]
    \centering
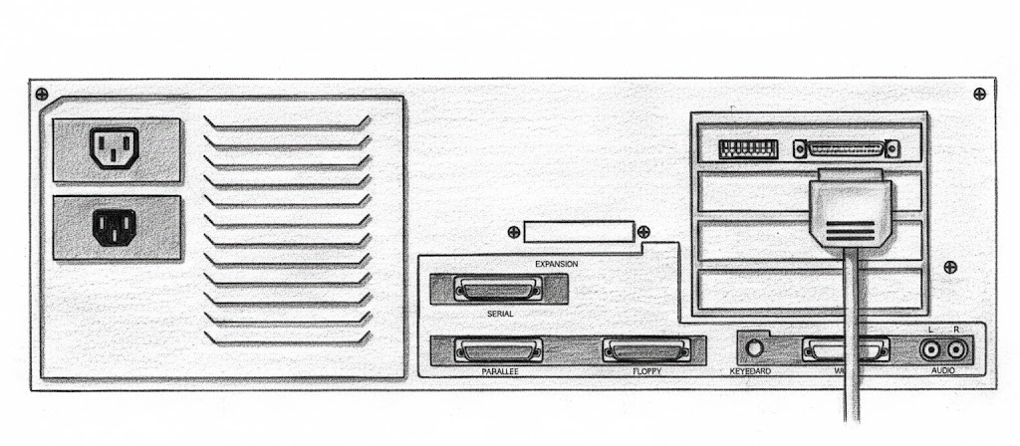
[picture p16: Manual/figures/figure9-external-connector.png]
    
    \caption{Connecting a Device to the External Connector}
    \label{fig:externalconnector}
\end{figure}

\textbf{Note:} The external connector is a high density 50-pin SCSI-2 female connector. SCSI devices with a different connector will require an adapter cable with a 50-pin SCSI-2 male connector on one end and an appropriate connector for the device on the other end. See ``External SCSI-2 Connector Description'' for the connector pinout information.

% =============================================================================
% CHAPTER 6: CONFIGURING A HARD DRIVE
% =============================================================================
\chapter{Configuring a Hard Drive}
\label{ch:configuring-hard-drive}

You do not have to reconfigure a previously used SCSI hard drive. If installing a new SCSI hard drive, follow these steps to complete the installation:

\begin{figure}[H]
    \centering
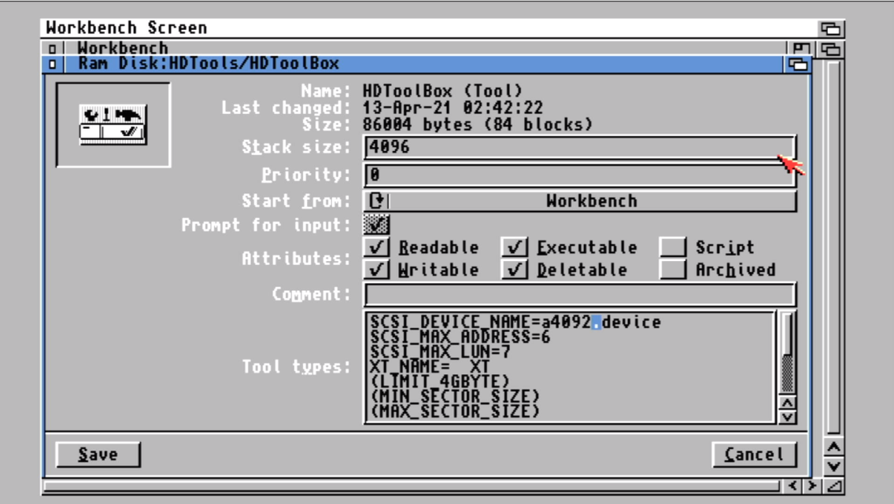
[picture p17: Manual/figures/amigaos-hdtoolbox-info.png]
    
    \caption{HDToolBox Information Window}
    \label{fig:hdtoolbox-info}
\end{figure}

\begin{enumerate}
    \item Select HDToolBox by clicking on it once.
    \item Open ``Information'' from the Icons menu.
    \item Change the \texttt{SCSI\_DEVICE\_NAME} tooltype from \texttt{scsi.device}\\to \texttt{a4092.device}.
\end{enumerate}

After making this change, HDToolBox will be able to detect the SCSI devices attached to your A4092 SCSI controller.

% dummy new page to get page count to 36
\newpage
\mbox{}
\newpage

% =============================================================================
% CHAPTER 7: EXTERNAL SCSI-2 CONNECTOR DESCRIPTION
% =============================================================================
\chapter{External SCSI-2 \newline Connector Description}
\label{ch:external-scsi2-connector}

\begin{figure}[ht]
    \centering
    
    \caption{External SCSI-2 Connector}
    \label{fig:scsi2connector}
\end{figure}

In the following pinout, a slash (/) preceding the signal name indicates that the signal is active low.

{
\small
\centering
\begin{longtable}{cl|cl}
\toprule
\textbf{Pin} & \textbf{Signal Name} & \textbf{Pin} & \textbf{Signal Name} \\ \midrule
\endfirsthead
\toprule
\textbf{Pin} & \textbf{Signal Name} & \textbf{Pin} & \textbf{Signal Name} \\ \midrule
\endhead

1 & Ground & 26 & /DB(0) \\
2 & Ground & 27 & /DB(1) \\
3 & Ground & 28 & /DB(2) \\
4 & Ground & 29 & /DB(3) \\
5 & Ground & 30 & /DB(4) \\
6 & Ground & 31 & /DB(5) \\
7 & Ground & 32 & /DB(6) \\
8 & Ground & 33 & /DB(7) \\
9 & Ground & 34 & /DB(P) \\
10 & Ground & 35 & Ground \\
11 & Ground & 36 & Ground \\
12 & Reserved & 37 & Reserved \\
13 & Open & 38 & TERMPWR \\
14 & Reserved & 39 & Reserved \\
15 & Ground & 40 & Ground \\
16 & Ground & 41 & /ATN \\
17 & Ground & 42 & Ground \\
18 & Ground & 43 & /BSY \\
19 & Ground & 44 & /ACK \\
20 & Ground & 45 & /RST \\
21 & Ground & 46 & /MSG \\
22 & Ground & 47 & /SEL \\
23 & Ground & 48 & /C/D \\
24 & Ground & 49 & /REQ \\
25 & Ground & 50 & /I/O \\
\bottomrule
\end{longtable}
}

% =============================================================================
% CHAPTER 8: THE A4092 BOOT DISK
% =============================================================================
\chapter{The A4092 Boot Disk}
\label{ch:boot-disk}

The A4092 comes with a boot disk containing utilities and the device driver. When you boot from this disk, you will see the main screen shown in Figure~\ref{fig:bootdisk}.

\begin{figure}[ht]
    \centering
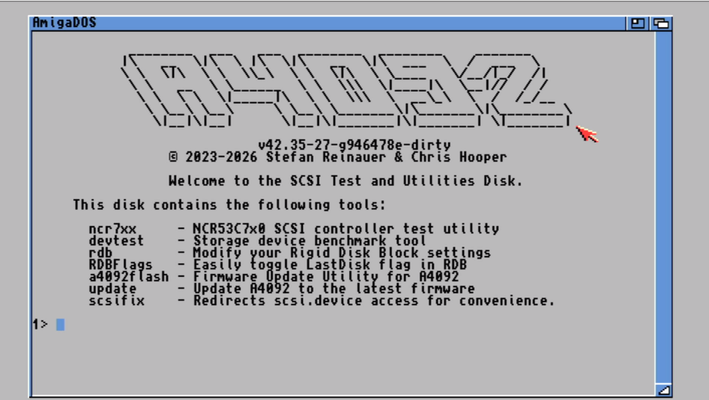
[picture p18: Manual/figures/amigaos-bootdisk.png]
    
    \caption{A4092 Boot Disk Main Screen}
    \label{fig:bootdisk}
\end{figure}

The boot disk includes the following utilities:

\begin{itemize}
    \item \textbf{ncr7xx} --- The factory test utility for A4091/A4092 controllers.
    \item \textbf{devtest} --- The best disk benchmarking utility for the Amiga.
    \item \textbf{rdb/RDBFlags} --- Utilities to modify the Rigid Disk Block of your disk. Handle with care.
    \item \textbf{a4092flash} --- The flash update utility for the A4092.
    \item \textbf{update} --- Shortcut to update the A4092 firmware.
    \item \textbf{scsifix} --- Redirects \texttt{scsi.device} accesses to \texttt{a4092.device} for convenience.
\end{itemize}

\section{Updating the Firmware}
\label{sec:updating-firmware}

The A4092 driver firmware can be updated directly from the boot disk. To update the firmware, run the \texttt{Update} program from the boot disk. This will display the update utility shown in Figure~\ref{fig:bootdisk-update}.

\begin{figure}[ht]
    \centering
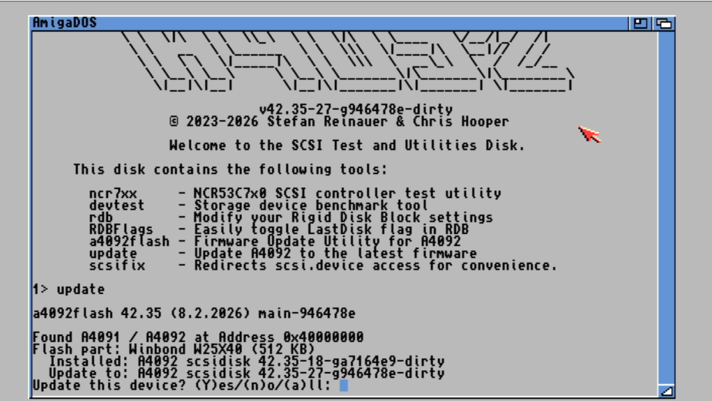
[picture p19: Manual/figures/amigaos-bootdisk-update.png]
    
    \caption{A4092 Firmware Update Utility}
    \label{fig:bootdisk-update}
\end{figure}

Follow the on-screen instructions to complete the firmware update. It is recommended to keep your A4092 firmware up to date to benefit from bug fixes and improvements.

\section{Command Line Firmware Operations}
\label{sec:cli-firmware-operations}

For advanced users, the \texttt{a4092flash} utility provides command-line access to firmware operations:

\begin{itemize}
    \item \texttt{a4092flash -P} --- Check the currently installed firmware version.
    \item \texttt{a4092flash -R backup.rom} --- Backup the current firmware to a file.
    \item \texttt{a4092flash -W a4092.rom} --- Write a new firmware image to the flash.
\end{itemize}

\newpage
\section{Filesystem Support}
\label{sec:filesystem-support}

The A4092 ROM includes CDVDFS, enabling booting from CD-ROM devices. This allows you to boot directly from AmigaOS installation CDs or other bootable media.

Support for FAT16/FAT32 filesystems is also available through the \texttt{fat95} filesystem, which enables reading PC-formatted drives and Zip disks. Adding FAT support requires building and flashing a custom firmware image---refer to the software repository documentation for instructions.

% =============================================================================
% CHAPTER 9: OPTIONAL ACCESSORIES
% =============================================================================
\chapter{Optional Accessories}
\label{ch:optional-accessories}

The A4092 can be enhanced with optional accessories that are available separately from the community. This list is not comprehensive; there are many other community projects worth exploring.

\section{ZuluSCSI}
\label{sec:zuluscsi}

ZuluSCSI is a SCSI device emulator that allows you to use SD cards or other modern storage media in place of traditional SCSI hard drives. The ZuluSCSI firmware and some hardware implementations are open source, though not all hardware implementations are. It connects to the A4092's internal SCSI ribbon cable just like any other SCSI device.

\section{SCSI Knife}
\label{sec:scsi-knife}

\begin{figure}[H]
    \centering
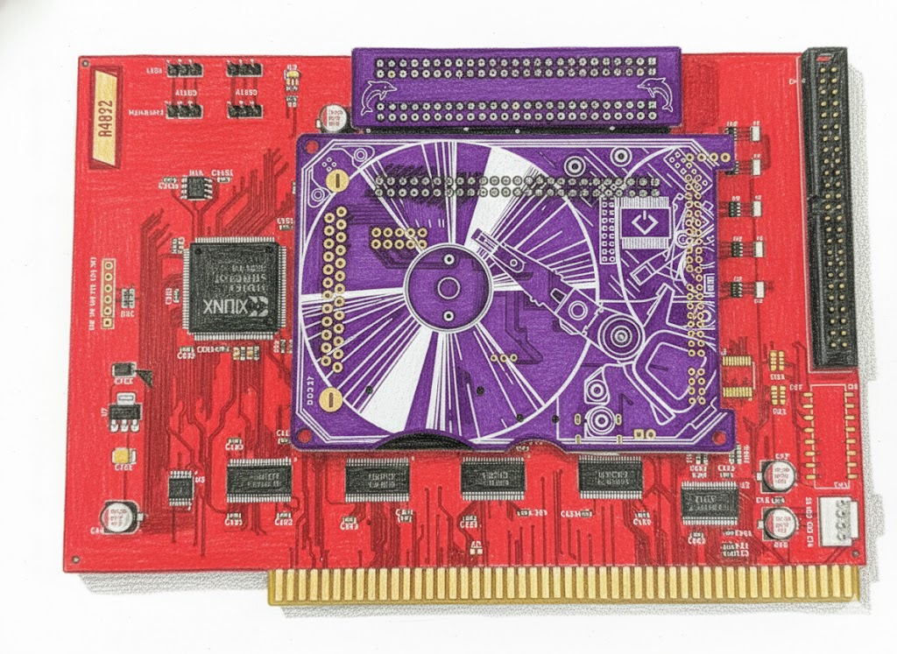
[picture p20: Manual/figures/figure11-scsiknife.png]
    
    \caption{SCSI Knife}
    \label{fig:scsiknife}
\end{figure}

The SCSI Knife is a compact ZuluSCSI-based device in a small form factor, designed to fit in tight spaces. It provides the same SCSI emulation capabilities as the full-size ZuluSCSI.

\section{A4092 SCSI Knife Mounting Adapter}
\label{sec:scsi-knife-mounting-adapter}

An optional mounting adapter is available that allows you to attach a SCSI Knife directly to the A4092 board. This provides a clean, integrated solution for adding solid-state SCSI storage to your system without taking up drive bay space.

The mounting adapter connects to the A4092's internal SCSI connector and positions the SCSI Knife securely on the board. Design files are available at \url{https://github.com/A4091/A4092/tree/main/Kicad/Flipper}.

% =============================================================================
% BACK COVER
% =============================================================================
% Add blank page if needed to ensure even page count
\ifodd\value{page}
    \newpage
    \thispagestyle{fancy}
    \fancyhf{}
    \fancyhead[LE,RO]{\textbf{A4092 User's Guide}}
    \fancyfoot[C]{\thepage}
    \null
\fi

% Inside back cover (white, empty)
\newpage
\thispagestyle{empty}
\null

% Back cover (black)
\newpage
\newpagecolor{boxblack}
\thispagestyle{empty}
\null

\end{document}

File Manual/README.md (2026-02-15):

# A4092 manual

This is the manual for the A4092 SCSI-2 host controller.

## Requirements

Building the manual requires:

- A LaTeX distribution with `pdflatex` and `tlmgr` (e.g. [MacTeX](https://www.tug.org/mactex/) on macOS)
- [Scribus](https://www.scribus.net/) for SVG-to-CMYK-PDF conversion
- Python 3 for the `svg2cmyk.py` helper script

### LaTeX packages (macOS)

```
sudo tlmgr update --self
sudo tlmgr install titlesec pagecolor helvetic svg framed transparent enumitem
```

## How to build

```
make
```

Output: `A4092-manual.pdf`

To remove all generated files:

```
make clean
```

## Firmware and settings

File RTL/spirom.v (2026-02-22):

`timescale 1ns / 1ps
//////////////////////////////////////////////////////////////////////////////////
// Company:
// Engineer:
//
// Create Date:    20:21:44 08/03/2025
// Design Name:
// Module Name:    spirom
// Project Name:
// Target Devices:
// Tool versions:
// Description:
//
// Dependencies:
//
// Revision:
// Revision 0.01 - File Created
// Additional Comments:
//
//////////////////////////////////////////////////////////////////////////////////
module spirom(
    input clk,
    input IORST_n,
    input romcycle,
    input [22:2] addr,
    input DOE,
    input [3:0] DS_n,
    input READ,
    input FC2,
    output reg dtack = 0,
    output reg spi_read = 0,
    output reg [7:0] spi_dataout = 0,
    input [7:0] spi_datain,
    output reg SPI_CLK = 0,
    output reg SPI_CS_n = 1,
    output reg SPI_MOSI = 0,
    input SPI_MISO
    );

    localparam  SPI_IDLE    =  2'b00,
                SPI_N       =  2'b01,
                SPI_P       =  2'b10,
                SPI_DTACK   =  2'b11;

    (* fsm_encoding = "user" *)reg [1:0] spi_state = SPI_IDLE;

    reg [7:0] shiftreg = 0;
    reg [5:0] cnt = 6'd40;
    reg close = 1'b1;

    reg romcycle_sync = 0;
    reg doe_sync = 0;
    reg DS_sync = 0;

    wire SPI_ROM;
    wire SPI_PORT_WRITE_HOLD;
    wire SPI_PORT_WRITE_END;
    wire SPI_PORT_READ_HOLD;
    wire SPI_PORT_READ_END;

    assign SPI_ROM = &addr[22:6] ? 0 : 1;                                         // $000000 -$7fffbf
    assign SPI_PORT_WRITE_HOLD = (!READ && ({addr[7:2],2'b00} == 8'hc0)) ? 1 : 0; // $7fffc0
    assign SPI_PORT_WRITE_END = (!READ && ({addr[7:2],2'b00} == 8'hd0)) ? 1 : 0;  // $7fffd0
    assign SPI_PORT_READ_HOLD = (READ && ({addr[7:2],2'b00} == 8'he0)) ? 1 : 0;   // $7fffe0
    assign SPI_PORT_READ_END = (READ && ({addr[7:2],2'b00} == 8'hf0)) ? 1 : 0;    // $7ffff0

    always @ (negedge IORST_n, posedge clk) begin
        if (!IORST_n) begin
            romcycle_sync <= 0;
            doe_sync <= 0;
            DS_sync <= 0;
        end else begin
            romcycle_sync <= romcycle;
            doe_sync <= DOE;
            DS_sync <= ~&DS_n;
        end
    end

    always @ (negedge IORST_n, posedge clk) begin
        if (!IORST_n) begin
            cnt <= 6'd40;
            spi_read <= 0;
            dtack <= 0;
            SPI_CLK <= 0;
            SPI_CS_n <= 1;
            SPI_MOSI <= 0;
            close <= 1;
            spi_dataout <= 0;
            spi_state <= SPI_IDLE;
        end else begin
            spi_read <= 0;
            dtack <= 0;
            SPI_CLK <= 0;
            case (spi_state)
            SPI_IDLE : begin
                spi_state <= SPI_IDLE;
                close <= 1;
                cnt <= 8;
                shiftreg <= spi_datain;
                if (romcycle_sync) begin
                    if (SPI_ROM) begin                      // $000000 - $7fffbf
                        SPI_CS_n <= 1'b1;
                        shiftreg <= 8'h03;
                        cnt <= 40;
                        if (READ) begin
                            spi_state <= SPI_N;             // READ -> Start SPI read command
                        end else begin
                            spi_state <= SPI_DTACK;         // WRITE -> immediately end ZIII Cycle
                        end
                    end else if (SPI_PORT_READ_END) begin   // $7ffff0
                        spi_state <= SPI_N;
                    end else if (SPI_PORT_READ_HOLD) begin  // $7fffe0
                        close <= 0;
                        spi_state <= SPI_N;
                    end else if (SPI_PORT_WRITE_END) begin  // $7fffd0
                        if (doe_sync && DS_sync) begin      // wait for DOE and DS before start SPI cycle
                            spi_state <= SPI_N;
                        end
                    end else if (SPI_PORT_WRITE_HOLD) begin // $7fffc0
                        if (doe_sync && DS_sync) begin      // wait for DOE and DS before start SPI cycle
                            close <= 0;
                            spi_state <= SPI_N;
                        end
                    end else begin
                        spi_state <= SPI_DTACK;             // all other -> immediately end ZIII Cycle
                    end
                end
            end

            SPI_N : begin
                SPI_CS_n <= 0;
                if (cnt == 0) begin
                    SPI_MOSI <= 0;
                    spi_dataout <= shiftreg;
                    spi_read <= READ;
                    spi_state <= SPI_DTACK;
                end else begin
                    SPI_MOSI <= shiftreg[7];
                    spi_state <= SPI_P;
                end
            end

            SPI_P : begin
                SPI_CLK <= 1;
                case (cnt)
                    33 :     shiftreg <= {3'b000, addr[22:18]};
                    25 :     shiftreg <= addr[17:10];
                    17 :     shiftreg <= addr[9:2];
                     9 :     shiftreg <= 0;
                    default: shiftreg <= {shiftreg[6:0], SPI_MISO};
                endcase
                cnt <= cnt - 1;
                spi_state <= SPI_N;
            end

            SPI_DTACK : begin
                SPI_CS_n <= close;
                if (!romcycle_sync) begin
                    spi_read <= 0;
                    dtack <= 0;
                    spi_state <= SPI_IDLE;
                end else begin
                    spi_read <= READ;
                    dtack <= 1;
                    spi_state <= SPI_DTACK;
                end
            end
            endcase
        end
     end

endmodule

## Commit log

2026-01-09 A4092 Schematics Revision C
    - Power U5 / 74LVC07 from 3.3V rail
    - Use ABOEH for 1OEAB on U4 / 74ABT16543
    - Add bypass capacitor C501 for U5 / 74LVC07
    - Remove EMI filters and capacitors from SCSI lines. They
    are a net negative for signal integrity
    - Remove DIP switch circuit as all options are controlled
    by the CPLD / AutoConfig ROM now.
    - Remove parallel flash memory, as SPI works reliably and
    is significantly easier to source.
    - Remove all ferrite beads from signal lines, as these were
    populated with 0 Ohm resistors in all Proto devices.
    - Mark power connector and 12V capacitor as DNP
    [A4092.kicad_sch, Termination.kicad_sch, flash.kicad_sch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]
2026-01-09 Update PCB from Schematic
2026-01-09 CPLD: Mark ROM_* as NC
    The parallel flash is gone, mark the pins as unconnected.
    [cpld.kicad_sch]
2026-01-09 Update PCB from Schematics
2026-01-10 Fix JTAG header
    [cpld.kicad_sch]
2026-01-11 U14: Switch to wider SPI footprint
    This will let builders use wide or small SPI flash parts.
    [cpld.kicad_sch]
2026-01-11 Don't show DNP parts in 3D view
    [cpld.kicad_sch]
2026-01-12 Mark unneeded pull-up resistors DNP
    [scsi2.kicad_sch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]
2026-01-18 Switch to Littelfuse SMDC185F/33-2
    Previously used JDTfuse ASMD2920-185 but I have 200
    pieces of Littelfuse SMDC185F/33-2 consigned.
    [power.kicad_sch]
2026-01-19 Reduce backpanel size
    [A4092-backpanel.kicad_pcb]
2026-01-23 Update Backpanel
    - Fix part numbers and orientation
    - Shift IDC50 connector up to get out of the way of the Zorro
    daughterboard and align better with the 4092 connector
    [A4092-backpanel.kicad_pcb, A4092-backpanel.kicad_sch]
2026-01-24 Fix BOM visibility on some parts
    [power.kicad_sch]
2026-02-07 Remove unused libraries and centralize lib-tables
    Remove 11 symbol/footprint libraries and associated 3D models that
    are no longer referenced by any active sub-project:
    - 219_8MST, 350543_1, 39SF010-TSOP, 74ACT521MTCX, 74FCT16543
    - ATF1508AS, CA0612KRNPO9BN101, CY74FCT543ATQCT, DA1206D600R-10
    - SN74ABT16374ADGGR, SN74F244DB
    Also remove the Studies/ layout studies (A4092_0418, A4092_0419)
    which were the only consumers of some of these libraries, along with
    orphaned 3D models (219-8M.stp, 219-8M-2.stp, BO_CAY16.stp,
    CA0612KRNPO9BN101.stp, CA064X101J5GAC7800.step, DA1206D600R-10.stp).
    Consolidate fp-lib-table and sym-lib-table into Libraries/ and replace
    per-project copies with relativ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
    [A4092_0418.kicad_pcb, A4092_0419.kicad_pcb]
2026-02-07 Add A4000D HPDB50 bracket design
    Add OpenSCAD source and generated STL for the A4000D HPDB50
    connector mounting bracket.
    [a4000d_hpdb50.scad, a4000d_hpdb50.stl]
2026-02-07 Fix footprint references in schematics
    [zorro3.kicad_sch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]
2026-02-07 Update PCB render to latest revision
2026-02-07 Rename brackets -> Brackets
    [a4000d_hpdb50.scad, a4000d_hpdb50.stl]
2026-02-15 Add REV-C Gerbers
    [bom.csv, designators.csv, positions.csv]
2026-02-15 Add Terminator STLs for A4092 active terminator case
    [A4092_terminator.scad]
2026-02-15 Add Makefile to Brackets
2026-02-21 RTL: Improve DMA state machine timing and add A4770 support
    Split SCSI_DS_n into separate A4092SCSI_DS_n (P32) and A4770SCSI_DS_n
    (P45) pins, driving only the active variant and tri-stating the other,
    as the pin mapping was changed between designs.
    Move autoconfig identity parameters (manufacturer ID, product ID, serial
    number, ROM vector) out of the autoconfig module and into the top-level
    module as localparam constants, preparing for per-board configuration.
    Fix the DMA master state machine (dmamaster.v):
    - Replace blocking assignments with non-blocking assignments in clocked
    always blocks, fixing potential simulation/synthesis mismatches.
    - Rework async resets: use IORST_n or efcs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
    [spirom.v]
2026-02-22 RTL: replace 40-bit SPI mux with 8-bit shift register
    Replace the 40-to-1 multiplexer that drove MOSI from a combined
    {command, address, data} wire indexed by the bit counter with an 8-bit
    shift register that is reloaded at byte boundaries.
    The old design used readcmd[cnt-1] to select one of 40 bits per SPI
    clock, creating a wide mux that exceeded the 54-input limit of a single
    CPLD function block. The fitter had to borrow product terms from other
    FBs, degrading timing.
    MOSI is now always driven from shiftreg[7]. During the clock-high phase
    (SPI_P), a case statement on the counter loads the next address byte at
    the appropriate boundary (cnt 33/25/17/9), and the default case performs
    the no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
    [spirom.v]

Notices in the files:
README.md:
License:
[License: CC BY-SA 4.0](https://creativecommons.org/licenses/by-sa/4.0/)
